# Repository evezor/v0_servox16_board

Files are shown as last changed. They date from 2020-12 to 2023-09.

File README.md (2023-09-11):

# Servo x16 Board
*please note this board has been deprecated.

This board uses the Evezor Stamp STMF405 MCU

source: https://github.com/evezor/Evezor-Stamp-STMF405

An edge board containing a PCA9685 driver chip capable of controlling 16 servos or LEDs. The board also contains 2 pushbuttons and a dpad for easy control/ debugging. 
Servo power must be supplied from external source

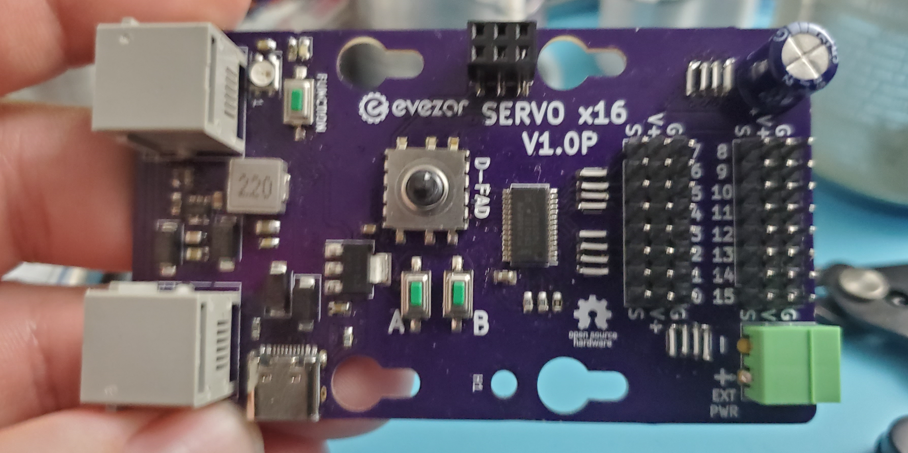
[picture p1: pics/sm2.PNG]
sm


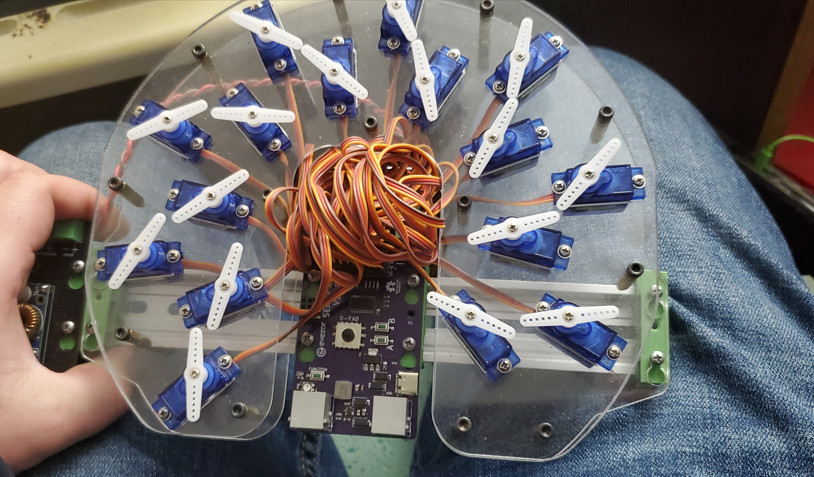
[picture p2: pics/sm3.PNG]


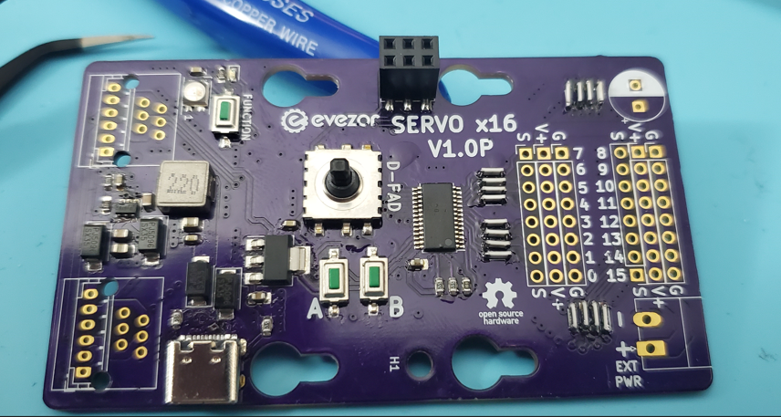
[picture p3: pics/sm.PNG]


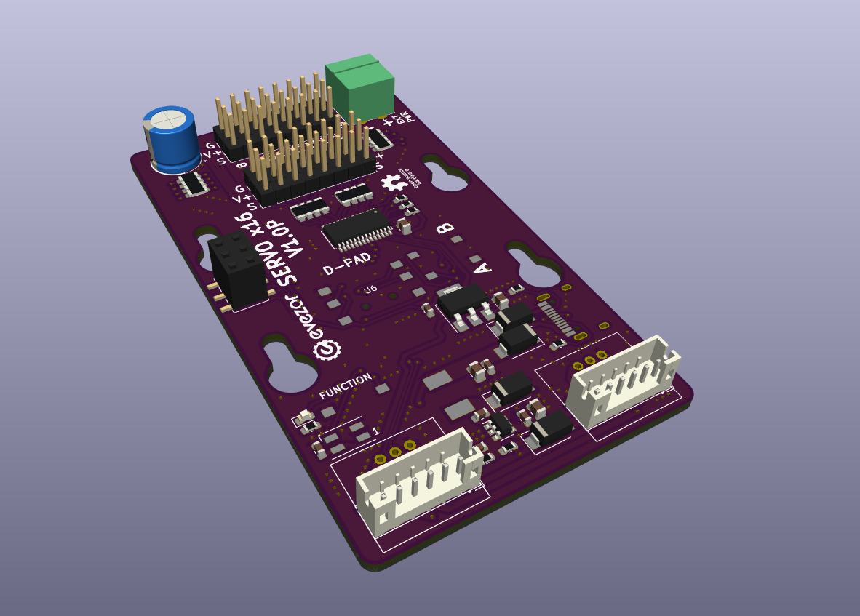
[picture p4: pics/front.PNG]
front


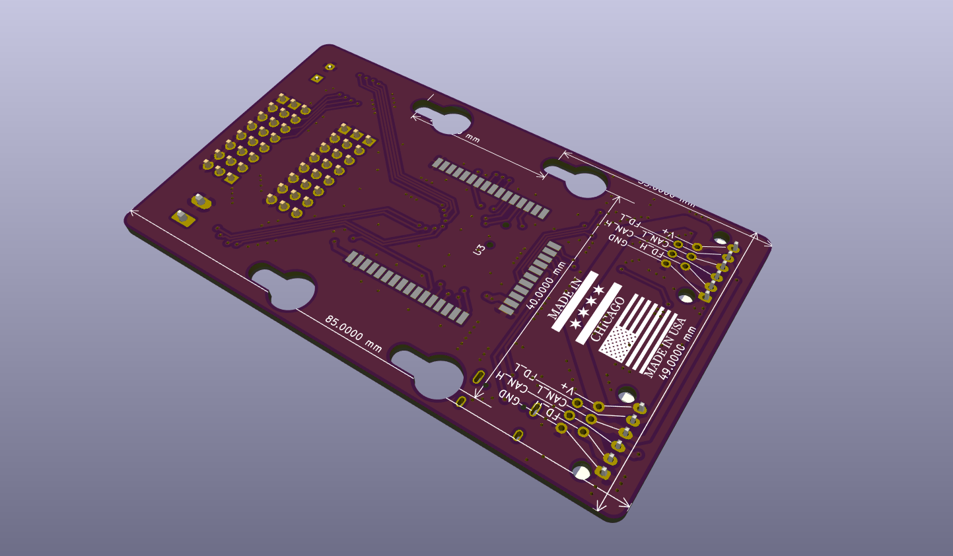
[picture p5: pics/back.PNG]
back


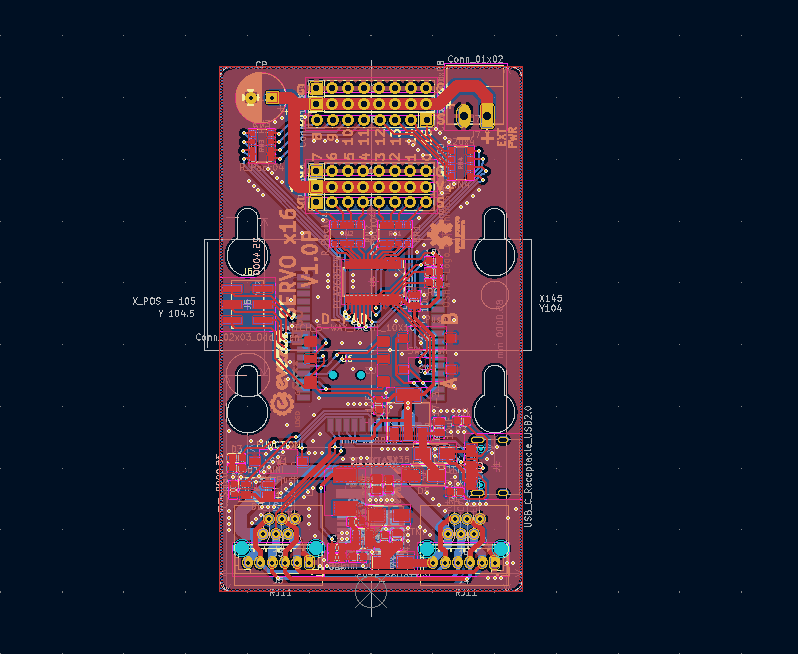
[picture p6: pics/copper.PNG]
copper


sch

source files can be found here: https://github.com/evezor/v0_servox16_board

Evezor® and all associated marks, logos, and designs are registered trademarks and protected by copyright. Unauthorized use or reproduction of these trademarks and copyrighted materials is strictly prohibited.

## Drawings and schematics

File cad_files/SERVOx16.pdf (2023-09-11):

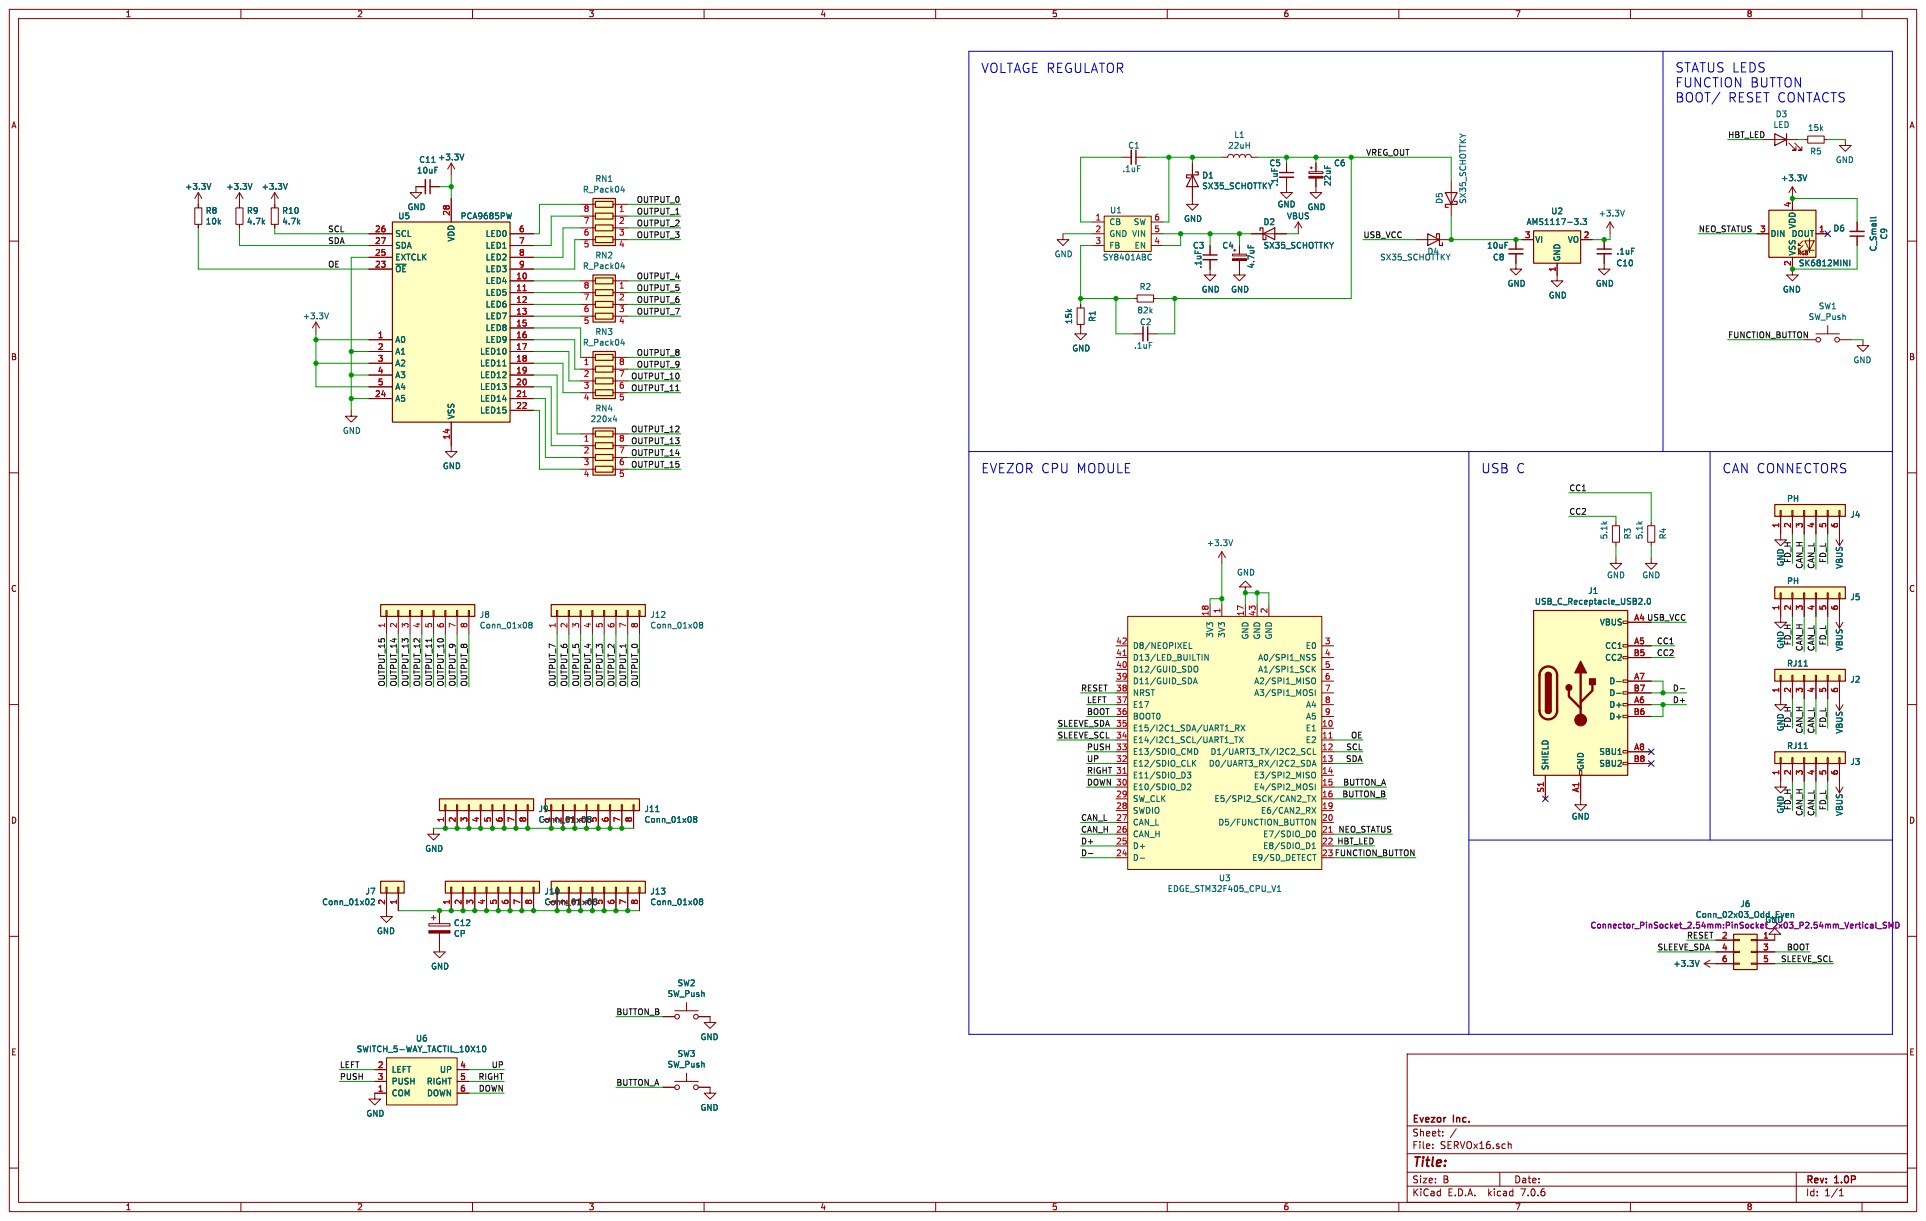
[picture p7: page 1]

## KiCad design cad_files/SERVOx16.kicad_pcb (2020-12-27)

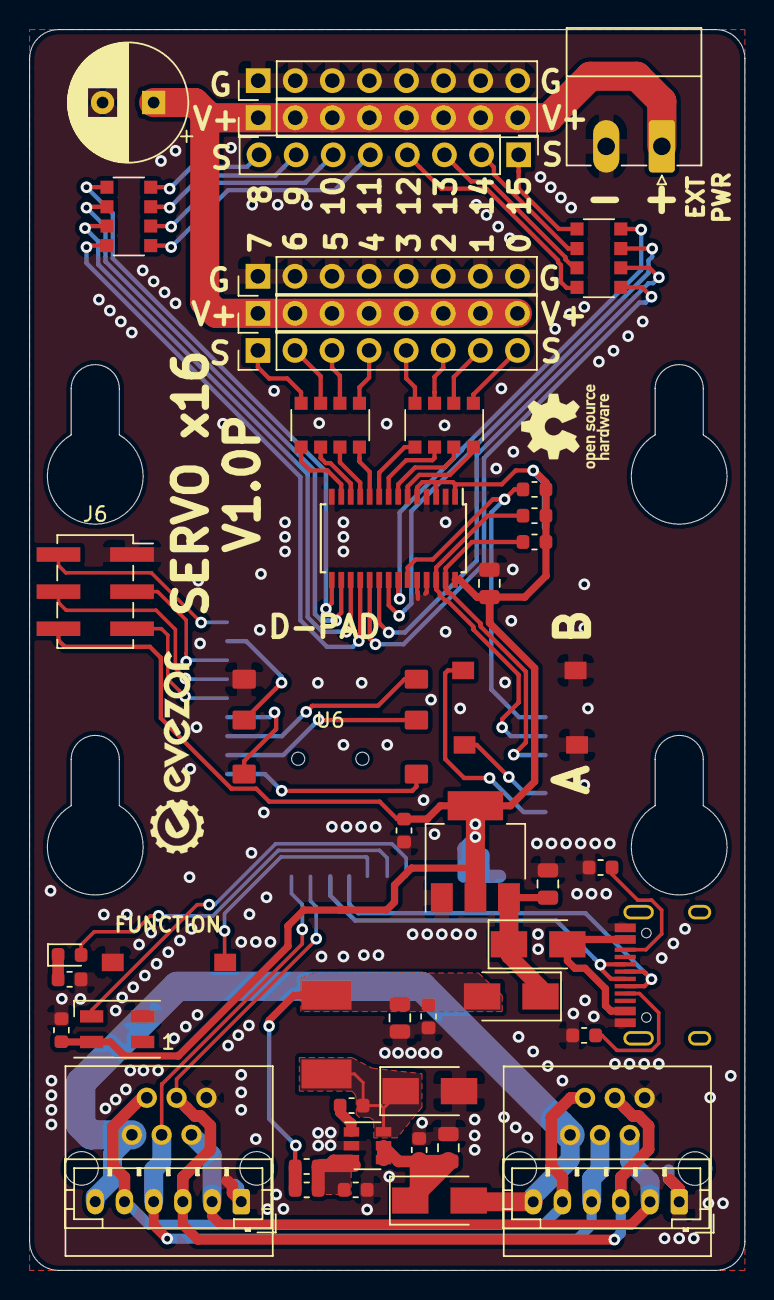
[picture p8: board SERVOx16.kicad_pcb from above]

Board: 2 copper layers, 49.0 x 85.0 mm, 51 parts (1 on the bottom side), 69 nets.

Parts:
C1, C2, C3, C5, C10: .1uF; C_0603_1608Metric
C4: 4.7uF; C_0805_2012Metric
C6: 22uF; C_0805_2012Metric
C8, C11: 10uF; C_0805_2012Metric
C9: C_Small; C_0603_1608Metric
C12: CP; CP_Radial_D8.0mm_P3.50mm
D1, D2, D4, D5: SX35_SCHOTTKY; D_SMA
D3: LED; LED_0603_1608Metric
D6: SK6812MINI; LED_SK6812MINI_PLCC4_3.5x3.5mm_P1.75mm
J1: USB_C_Receptacle_USB2.0; USB_C_Receptacle_HRO_TYPE-C-31-M-12
J2, J3: RJ11; RJ11_C189747_Horizontal
J4, J5: PH; JST_PH_B6B-PH-K_1x06_P2.00mm_Vertical
J6: Conn_02x03_Odd_Even; PinSocket_2x03_P2.54mm_Vertical_SMD
J7: Conn_01x02; PhoenixContact_MC_1,5_2-G-3.81_1x02_P3.81mm_Horizontal
J8, J9, J10, J11, J12, J13: Conn_01x08; PinHeader_1x08_P2.54mm_Vertical
L1: 22uH; INDUCTOR_7.5X6.6_GCDA0630-220MC
R1, R5: 15k; R_0603_1608Metric
R2: 82k; R_0603_1608Metric
R3, R4: 5.1k; R_0603_1608Metric
R8: 10k; R_0603_1608Metric
R9, R10: 4.7k; R_0603_1608Metric
RN1, RN2, RN3: R_Pack04; R_Array_Convex_4x1206
RN4: 220x4; R_Array_Convex_4x1206
SW1, SW2, SW3: SW_Push; SWITCH_2x3_SMD_TACTILE_GREEN
U1: SY8401ABC; SOT-23-6
U2: AMS1117-3.3; SOT-223-3_TabPin2
U3: EDGE_STM32F405_CPU_V1; EDGE_STAMP
U5: PCA9685PW; TSSOP-28_4.4x9.7mm_P0.65mm
U6: SWITCH_5-WAY_TACTIL_10X10; SWITCH_5WAY_10x10

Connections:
+3V3: C9.2, C10.1, C11.1, D6.4, J6.6, R8.1, R9.1, R10.1, U2.2, U3.1, U3.18, U5.1, U5.3, U5.5, U5.28
/BOOT: J6.3, U3.36
/BUTTON_A: SW3.1, U3.15
/BUTTON_B: SW2.1, U3.16
/CAN_H: J2.3, J3.3, J4.3, J5.3, U3.26
/CAN_L: J2.4, J3.4, J4.4, J5.4, U3.27
/CC1: J1.A5, R4.1
/CC2: J1.B5, R3.1
/D+: J1.A6, J1.B6, U3.25
/D-: J1.A7, J1.B7, U3.24
/DOWN: U3.30, U6.6
/FD_H: J2.2, J3.2, J4.2, J5.2
/FD_L: J2.5, J3.5, J4.5, J5.5
/FUNCTION_BUTTON: SW1.1, U3.23
/HBT_LED: D3.2, U3.22
/LEFT: U3.37, U6.2
/NEO_STATUS: D6.3, U3.21
/OE: R8.2, U3.11, U5.23
/OUTPUT_0: J12.8, RN1.1
/OUTPUT_1: J12.7, RN1.2
/OUTPUT_2: J12.6, RN1.3
/OUTPUT_3: J12.5, RN1.4
/OUTPUT_4: J12.4, RN2.1
/OUTPUT_5: J12.3, RN2.2
/OUTPUT_6: J12.2, RN2.3
/OUTPUT_7: J12.1, RN2.4
/OUTPUT_8: J8.8, RN3.8
/OUTPUT_9: J8.7, RN3.7
/OUTPUT_10: J8.6, RN3.6
/OUTPUT_11: J8.5, RN3.5
/OUTPUT_12: J8.4, RN4.8
/OUTPUT_13: J8.3, RN4.7
/OUTPUT_14: J8.2, RN4.6
/OUTPUT_15: J8.1, RN4.5
/PUSH: U3.33, U6.3
/RESET: J6.2, U3.38
/RIGHT: U3.31, U6.5
/SCL: R10.2, U3.12, U5.26
/SDA: R9.2, U3.13, U5.27
/SLEEVE_SCL: J6.5, U3.34
/SLEEVE_SDA: J6.4, U3.35
/UP: U3.32, U6.4
/USB_VCC: D4.2, J1.A4, J1.A9, J1.B4, J1.B9
/VREG_OUT: C2.1, C5.1, C6.1, D5.2, L1.2, R2.1
GND: C3.2, C4.2, C5.2, C6.2, C8.2, C9.1, C10.2, C11.2, C12.2, D1.2, D6.2, J1.A1, J1.A12, J1.B1, J1.B12, J2.1, J3.1, J4.1, J5.1, J6.1, J7.2, J9.1, J9.2, J9.3, J9.4, J9.5, J9.6, J9.7, J9.8, J11.1, J11.2, J11.3, J11.4, J11.5, J11.6, J11.7, J11.8, R1.1, R3.2, R4.2, R5.1, SW1.2, SW2.2, SW3.2, U1.2, U2.1, U3.2, U3.17, U3.43, U5.2, U5.4, U5.14, U5.24, U5.25, U6.1
unnamed: C1.1, D1.1, L1.1, U1.6
unnamed: C1.2, U1.1
unnamed: C2.2, R1.2, R2.2, U1.3
unnamed: C3.1, C4.1, D2.1, U1.4, U1.5
unnamed: C8.1, D4.1, D5.1, U2.3
unnamed: C12.1, J7.1, J10.1, J10.2, J10.3, J10.4, J10.5, J10.6, J10.7, J10.8, J13.1, J13.2, J13.3, J13.4, J13.5, J13.6, J13.7, J13.8
unnamed: D3.1, R5.2
unnamed: RN1.5, U5.9
unnamed: RN1.6, U5.8
unnamed: RN1.7, U5.7
unnamed: RN1.8, U5.6
unnamed: RN2.5, U5.13
unnamed: RN2.6, U5.12
unnamed: RN2.7, U5.11
unnamed: RN2.8, U5.10
unnamed: RN3.1, U5.15
unnamed: RN3.2, U5.16
unnamed: RN3.3, U5.17
unnamed: RN3.4, U5.18
unnamed: RN4.1, U5.19
unnamed: RN4.2, U5.20
unnamed: RN4.3, U5.21
unnamed: RN4.4, U5.22
VBUS: D2.2, J2.6, J3.6, J4.6, J5.6

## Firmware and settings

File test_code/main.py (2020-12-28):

#Servo x16 v1.0p test code

######################
#Notes
#Servos min=650 max=2300
servo_max = 650
servo_min = 2300

from machine import Pin, I2C
from pyb import CAN
import utime
import servo
#import pca9685

print("starting Servo x16 v1.1p test code")
print("v1.0")
print("initializing")
can = CAN(1, CAN.NORMAL)
can.setfilter(0, CAN.LIST16, 0, (123, 124, 125, 126))

#sleep to let pca9685 wake up
utime.sleep_ms(500)
i2c = I2C(2, freq=1000000)


#Setup Pins
HBT_LED = Pin("E8", Pin.OUT)
FUNC_BUTTON = Pin("SD_DETECT", Pin.IN, Pin.PULL_UP) 
NEO_STATUS = Pin("E7", Pin.OUT)

BUTTON_A = Pin("E4", Pin.IN, Pin.PULL_UP)
BUTTON_B = Pin("E5", Pin.IN, Pin.PULL_UP)

UP = Pin("E12", Pin.IN, Pin.PULL_UP)
DOWN = Pin("E10", Pin.IN, Pin.PULL_UP)
LEFT = Pin("E17", Pin.IN, Pin.PULL_UP)
RIGHT = Pin("E11", Pin.IN, Pin.PULL_UP)
DPAD_PUSH = Pin("E13", Pin.IN, Pin.PULL_UP)



#OE pin is the 'enable' pin for the outputs. ACTIVE LOW!
OE = Pin("E2", Pin.OUT)
OE.value(0)

#Setup hbt timer
hbt_state = 0
hbt_interval = 500
start = utime.ticks_ms()
next_hbt = utime.ticks_add(start, hbt_interval)
HBT_LED.value(hbt_state)

#Setup pca9685
#pca = pca9685.PCA9685(i2c)
servos = servo.Servos(i2c)


print("setup complete")


def chk_hbt():
    global next_hbt
    global hbt_state
    now = utime.ticks_ms()
    if utime.ticks_diff(next_hbt, now) <= 0:
        if hbt_state == 1:
            hbt_state = 0
            HBT_LED.value(hbt_state)
            #print("hbt")
        else:
            hbt_state = 1
            HBT_LED.value(hbt_state)  
        
        next_hbt = utime.ticks_add(next_hbt, hbt_interval)

def send():
    can.send('servoX16', 123)   # send a message with id 123
    
def get():
    mess = can.recv(0)
    print(mess)
    simple_test()    

def simple_test():
    move_all(servo_max)
    move_all(servo_min)
    
def move_all(us_delay):
    print("moving all servos to " + str(us_delay))
    for i in range(16):
        servos.position(i, us=us_delay)
        utime.sleep_ms(100)
    print("done")
        
while True:
    chk_hbt()
    if not (FUNC_BUTTON.value()):
        print("function button")
        send()
        simple_test()
        utime.sleep_ms(200)
        
    if not (BUTTON_A.value()):
        print("A button")        
        utime.sleep_ms(200)    

    if not (BUTTON_B.value()):
        print("B button")        
        utime.sleep_ms(200)    

    if not (UP.value()):
        print("UP button")        
        utime.sleep_ms(200)    

    if not (DOWN.value()):
        print("DOWN button")        
        utime.sleep_ms(200)    

    if not (LEFT.value()):
        print("LEFT button")  
        move_all(servo_min)
        utime.sleep_ms(200)    

    if not (RIGHT.value()):
        print("RIGHT button")
        move_all(servo_max)
        utime.sleep_ms(200)    

    if not (DPAD_PUSH.value()):
        print("DPAD_PUSH button")        
        utime.sleep_ms(200)    

    if(can.any(0)):
        get()

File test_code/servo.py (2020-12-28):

import pca9685
import math


class Servos:
    def __init__(self, i2c, address=0x55, freq=50, min_us=600, max_us=2400,
                 degrees=180):
        self.period = 1000000 / freq
        self.min_duty = self._us2duty(min_us)
        self.max_duty = self._us2duty(max_us)
        self.degrees = degrees
        self.freq = freq
        self.pca9685 = pca9685.PCA9685(i2c, address)
        self.pca9685.freq(freq)

    def _us2duty(self, value):
        return int(4095 * value / self.period)

    def position(self, index, degrees=None, radians=None, us=None, duty=None):
        span = self.max_duty - self.min_duty
        if degrees is not None:
            duty = self.min_duty + span * degrees / self.degrees
        elif radians is not None:
            duty = self.min_duty + span * radians / math.radians(self.degrees)
        elif us is not None:
            duty = self._us2duty(us)
        elif duty is not None:
            pass
        else:
            return self.pca9685.duty(index)
        duty = min(self.max_duty, max(self.min_duty, int(duty)))
        self.pca9685.duty(index, duty)

    def release(self, index):
        self.pca9685.duty(index, 0)
